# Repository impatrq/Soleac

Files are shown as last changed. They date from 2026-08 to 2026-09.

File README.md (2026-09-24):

<!DOCTYPE html>
<html>
<head>
    <meta charset="UTF-8">

</head>
<body>
    <h1><strong>Soleac</strong></h1>
<p align="center">
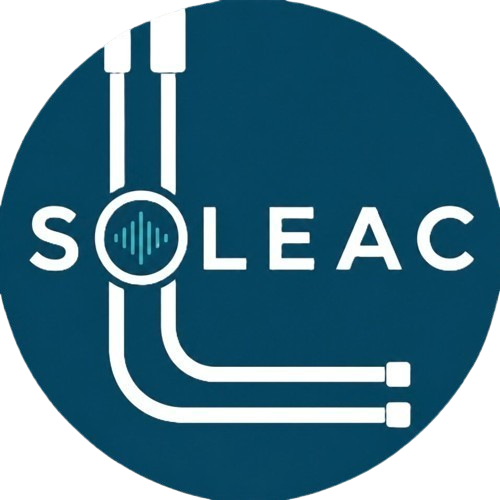
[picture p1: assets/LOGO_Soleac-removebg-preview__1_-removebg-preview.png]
Soleac
  
  &nbsp;&nbsp;&nbsp;&nbsp;
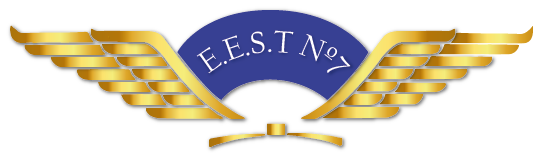
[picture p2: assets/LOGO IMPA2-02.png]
IMPA
  
</p>
</body>
  <h2><strong>Organizacion de archivos</strong></h2>
<em><li><b>Carpeta de campo</b>/Progreso y documentacion </li>
<li><b>Diseño 3D</b>/Diseños fisicos de herraminetas</li>
<li><b>Firmware</b>/Codigos implementados a los microcontroladores</li>
<li><b>Hardware</b></Esquematicos y PCBs</li>
<li><b>Assets</b>/Logotipos, README lockup</li></em>
<hr>
<body>
    <h2><strong>Que es Soleac y cómo funciona</strong></h2>
   <em><b>Soleac es un instrumento tecnologico detector de fugas de aire comprimido y gas. 
   <br>Mediante receptores de frecuencia tales cómo:</b>
   <li>Microfono MEMS SPH0641LU4H-1</li>
    <li>MURATA ma40s4r</li>
<b>Podemos captar fugas en caños, ya que estas generan una frecuencia de entre 20khz y 80khz dependiendo el tamaño.<br>Mediante el siguiente sensor:</b>
 <li>Sensor de gas MQ2</li>
 <b>Al acercar el instrumento, este sensor confirma si realmente hay una fuga, cabe aclarar que solo funciona sensando los siguientes gases:</b>
 <ul>
  <li>Gas Licuado de Petróleo</li>
  <li>Propano</li>
  <li>Metano</li>
  <li>Monóxido de carbono</li>
    <li>butano</li>
</ul>
<b>Si quisieras captar aire comprimido con este sensor, por ejemplo, no sirve y tendrias que usar los sensores de frecuencia.</b></em>
<hr>
<body>
    <h2><strong>Porque existe Soleac</strong></h2>
    <em><b>El instrumento Soleac surge de tres problematicas actuales:</b><br>
    La primera y mas importante es que solo existe una herramienta para los plomeros que les indique con precision donde hay una fuga sin tener que romper ni un ladrillo de pared, la problematica de esta herramienta es que es demasiado cara y ahi es donde entra soleac, presentando un precio que por lo menos este en el presupuesto de un plomero promedio. Llevando a estas herramientas detectores de fugas no solo a empresas grandes, si no tambien a empresas chicas y hogares.</em>
<hr>
<body>
    <h2><strong>Modelo Soleac</strong></h2>
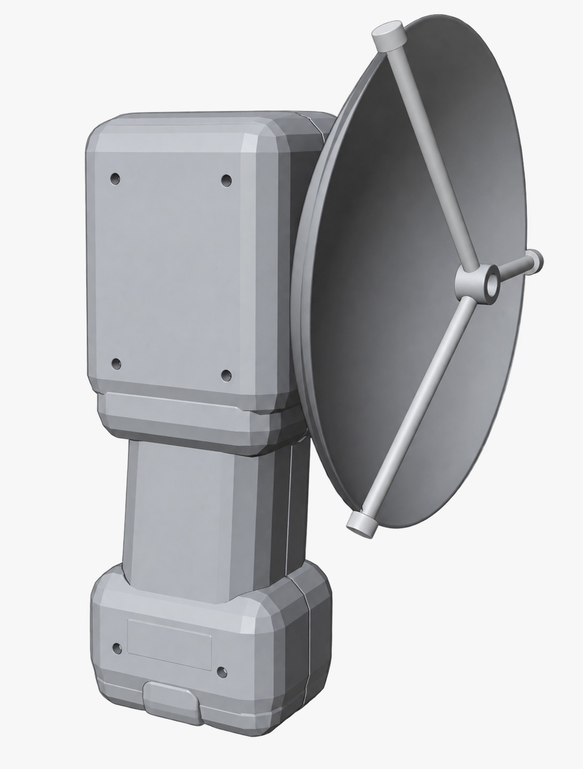
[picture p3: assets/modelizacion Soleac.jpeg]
Soleac

<hr>
<body>
  <h2><strong>Componentes principales del proyecto</strong></h2>
  <em><li>Esp32 S3 Touch Lcd 3.5B</li>
  <li>Microfono MEMS SPH0641LU4H-1</li>
  <li>MURATA ma40s4r</li>
  <li>sensor de gas MQ2</li></em>
</body>
<hr>

<body>
  <h3><strong>Contacto</strong></h3></body>


 

  <h3><strong>Otros proyectos</strong></h3></body>


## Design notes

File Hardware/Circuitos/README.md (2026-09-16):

# Soleac

## En esta carpeta se encuentra el hardware utilizado.
## MQ2-Soleac
MQ2-Back:
* Imagen de la placa de cobre MQ2 del lado de atras.
MQ2-Front:
*Imagen de la placa de cobre MQ2 del lado de adelante.
## Carpeta Placa Mems - SOLEAC
En esta carpeta se guardan los archivos de Kicad de los circuitos esquematicos y PCBs.
Para utilizarlos debes descargar Kicad para poder ver los circuitos y editarlos.
carpeta tal

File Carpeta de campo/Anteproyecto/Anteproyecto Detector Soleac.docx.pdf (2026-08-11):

Escuela de Educación Técnica Nº7
Taller Regional Quilmes
Prácticas Profesionalizantes: Especialidad Aviónica

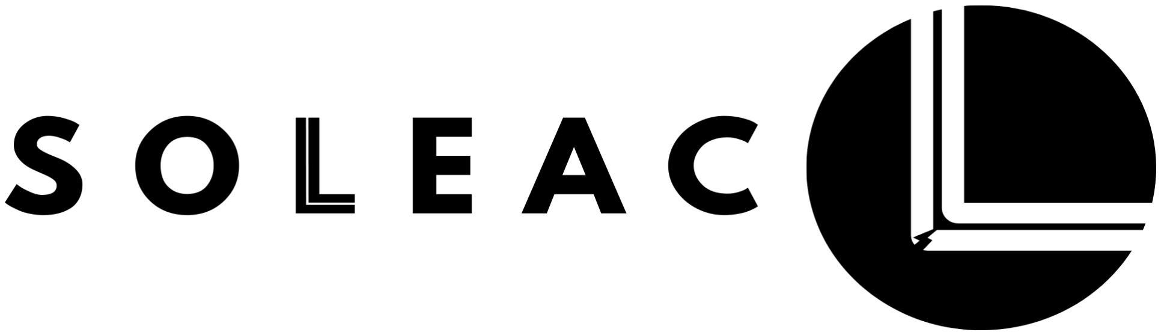
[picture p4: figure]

## Presentación de anteproyecto

## Título del proyecto: “Soleac”

Para pensar el nombre mezclamos tres palabras claves de nuestro proyecto, “Sound” (sonido en inglés), “Sol” (uno de nuestras tipos de alimentación) y “Leak” (Fuga/Derrame en inglés).

## Integrantes:

- Sanabria Caballero Federico ( federico sanabriacaballero )
- Solis Leonard Tobias ( tobias solisleonard )
- Rea Vera Jhonatan ( jhonatan reavera )
- Romero Julian ( julian romero )
- Paolo Valentino ( valentino paolo )

## Objetivo del proyecto:

El objetivo de este proyecto es ayudar a las Pymes, hogares e instalaciones con problemas de fugas en tuberías. Para lograrlo se va a armar un detector de fugas ultrasónico, que mediante sensores ultrasónicos va a poder medir si hay una fuga de gas o aire comprimido. Soleac ayudaría a cuidar el medio ambiente detectando más fácilmente las fugas de gas y aire comprimido y también a empresas/viviendas con ese problema.

## Utilidades del proyecto:

Nuestro proyecto está destinado a las viviendas con instalaciones de gas, a empresas/ fábricas o trabajadores independientes que trabajen con gas o aire comprimido

Las fugas de gas pueden representar pérdidas significativas, variando desde pequeñas ineficiencias hasta un 25% - 30% del volumen en sistemas industriales de aire comprimido, pudiendo superar el 50% en casos graves. En entornos domésticos, una fuga leve es inaceptable, mientras que el riesgo explosivo comienza con un 5% de gas en el aire, un caso reciente es la explosión en una metalúrgica en Tostado o la tragedia en un Polo Industrial en Ezeiza demuestran que las fugas de gas no solo afectan a los trabajadores, sino también a estructuras cercanas.

La OMS (Organización Mundial de la Salud) advierte que el gas deteriora la salud al reaccionar con otros contaminantes para formar ozono troposférico y partículas finas, responsables de muertes por enfermedades respiratorias. Nuestro proyecto ayuda a mejorar el medioambiente impidiendo la contaminación del aire mediante gas.

## Descripción del funcionamiento:

El proyecto consiste básicamente en usar 2 microfonos MEMS ultrasonicos que captaría una señal de 20kHz a 90 kHz, con ayuda de una antena parabólica, medimos y buscamos esas frecuencias ya que son las que usualmente genera la vibración de una fuga de gas o aire comprimido, los 2 sensores sensan la posición exacta o con un margen de error mínimo de donde esta la fuga, lo haríamos gracias a que los microfonos MEMS captan la información y con el tiempo que tarda en llegar la señal se calcula y se consigue la ubicación, el micrófono es muy sensible lo que logra que capte esas señales, las pasaremos por un filtro rechaza-bajos y rechaza-alto que capta las frecuencias anteriormente dichas, después la señal filtrada pasa por un filtrado por tiempo y por un atenuador para poder separar la señal de la fuga de todo el resto y posteriormente pasar por un amplificador con un integrado LM358, después de la etapa de amplificación la señal llega al microcontrolador ESP32 que procesa la información recibida con el ADC, mediante un programa que vamos a crear, y la envía al display LCD y a la aplicación del móvil que muestra la información de donde esta la fuga y de qué fluido se trata.

Para alimentar el detector de fugas va a contar baterías recargables que se cargan con una base de carga que se alimenta con energía solar o alimentación cotidiana (220V), que van a ser elegibles con un switch para usar la más conveniente en la situación que se encuentre el usuario.

## Análisis de factibilidad:

### - Programación del sistema

Integrante: Federico Sanabria Caballero ( federico sanabriacaballero )

Tareas principales:

Programar la lectura de los sensores ultrasónicos, analizar la intensidad de la señal recibida, establecer un umbral de detección de fugas, implementar el cambio de modo (entre gas o aire comprimido), controlar la pantalla LCD, activar alarmas sonoras, enviar datos al celular mediante WiFi y registrar datos en la tarjeta microSD.

Posibles problemáticas y soluciones:

- Ruido en las lecturas del sensor:

Los sensores ultrasónicos pueden captar vibraciones o interferencias.

Soluciones:

Aplicar promedios de lectura

Usar filtros digitales

Ajustar el umbral de detección

- Saturación del ADC

Si la señal amplificada es demasiado grande, el convertidor analógico digital puede saturarse.

Soluciones:

Ajustar la ganancia del amplificador

Usar un divisor de tensión.

- Problemas de sincronización entre sensores

Cuando se usan varios sensores, puede ser difícil comparar señales al mismo tiempo.

Soluciones:

Leer sensores en ciclos rápidos

Usar temporizadores del microcontrolador

- Aplicación de celular

Integrante: Julian Romero ( julian romero )

Tareas principales:

Diseñar la interfaz de la aplicación, recibir datos enviados por el detector y mostrarlos en tiempo real, mostrar alertas de fuga, indicar el sensor que detectó la fuga y mostrar intensidad de la señal.

Posibles problemáticas:

- Dificultad para conectar la app con el ESP32

Puede haber problemas de comunicación entre el celular y el dispositivo.

Soluciones:

Usar protocolos simples como HTTP o WebSocket

Probar primero con una página web local

- Problemas de compatibilidad con celulares

Distintos teléfonos pueden comportarse diferente.

Soluciones:

Usar herramientas multiplataforma

Realizar pruebas en varios dispositivos

- Latencia en la transmisión de datos

Si la conexión es lenta, la información puede tardar en llegar.

Soluciones:

Enviar datos solo cuando hay cambios importantes

Optimizar el tamaño de los mensajes

- Armado físico del dispositivo

Integrantes:

Tobias Solis Leonard ( tobias solisleonard )

Valentino Paolo ( valentino paolo )

Tareas principales:

Diseñar la carcasa del dispositivo, montar los sensores ultrasónicos, instalar la pantalla y botones, armar el sistema de alimentación, organizar el cableado interno y asegurar protección mecánica del circuito.

Posibles problemáticas:

- Posición incorrecta de los sensores

Si los sensores no están bien orientados, la detección puede fallar.

Soluciones:

Probar diferentes posiciones

Usar tubos o guías acústicas para direccionar el sonido

- Vibraciones del dispositivo

Las vibraciones externas pueden afectar la medición.

Soluciones:

Usar soportes de goma

Aislar el sensor del chasis

- Problemas de espacio interno

Muchos componentes pueden dificultar el montaje.

Soluciones:

Diseñar previamente la distribución interna

Usar separadores y soportes

- Diseño de esquemático

Integrante: Jhonatan Nauel Rea Vera ( jhonatan reavera )

Tareas principales:

Diseñar el circuito de amplificación, implementar el filtro pasa banda, conectar sensores al microcontrolador, diseñar la alimentación del sistema y agregar protecciones eléctricas

Posibles problemáticas:

- Diseño incorrecto del filtro

Si el filtro no está bien calculado, puede eliminar la señal de la fuga.

Soluciones:

Simular el circuito antes de construirlo

Verificar frecuencias de corte

- Problemas de ruido eléctrico

Las señales ultrasónicas son muy pequeñas y pueden contaminarse con ruido. Soluciones:

Usar capacitores de desacople

Separar circuitos analógicos y digitales

- Conexiones incorrectas

Errores en el esquemático pueden generar fallas en el circuito.

Solución:

Validar con el equipo antes de fabricar la PCB

- Diseño y armado de PCBs

Integrante: Jhonatan Nauel Rea Vera ( jhonatan reavera )

Tareas principales:
Convertir el esquemático en diseño de PCB, ubicar los componentes correctamente, diseñar pistas de conexión, optimizar el tamaño de la placa y preparar archivos de fabricación.

Posibles problemáticas

- Interferencias entre pistas

Las señales ultrasónicas pueden verse afectadas por ruido de otras líneas.

Soluciones:

Mantener pistas analogicas separadas

- Pistas finitas

Si las pistas son muy delgadas pueden romperse o calentarse.

Soluciones:

Usar ancho adecuado según corriente

Revisar reglas de diseño

- Error en la fabricación

Una PCB mal diseñada puede requerir rehacer la placa.

Soluciones:

Probar primero en protoboard

Revisar el diseño antes de realizarlo

## Costo del proyecto:

Componentes y materiales necesarios:

- Microfono MEMS ultrasonico | $12,50 - $18,00
- Sensores de gas | $4,00 - $6,50
- Panel solar | $10,00 - $35,00
- Display LCD | $6,00 - $9,00
- Componentes básicos (Resistencias, capacitores, transistores, etc.) | $5,00 - $10,00
- LM358 | $0,50 - $1,00
- Adaptador de 220V | $3,00 - $8,00
- Cable de osciloscopio | $15,00 - $25,00
- Filamento para impresión 3D | $18,00 - $24,00
- Protoboard | $5,00 - $8,00
- Placas de cobre | $3,00 - $6,00
- Costo total del proyecto | $82,00 - $150,50

## Análisis de costo/beneficio:

Básicamente Soleac tendría un costo y rentabilidad bastante alto para los estándares actuales que hay en el mismo rubro que este mismo se haya.

Esto se puede comprobar ya que un detector de fugas industrial ronda entre los $2000,00 -$4500,00 mientras que nuestro proyecto ronda entre los $85,50 - $156,00 aproximadamente según las regulaciones y costos que tendríamos durante el proceso de este mismo.

Nuestra idea principal se trataría de que cooperadora pueda invertir en nosotros o en todo caso buscar sponsors qué se dedican a esto mismo, como empresas que refinan gas ayudarían en este proyecto por la única razón que este mismo si llega a ser funcional y rentable estas empresas usarían este mismo proyecto y gastarán menos dinero por ende para ellos generaría una ganancia y reemplazamos algo en el mercado qué tiene un mayor costo y rentabilidad.

## Diagrama en bloques del prototipo:

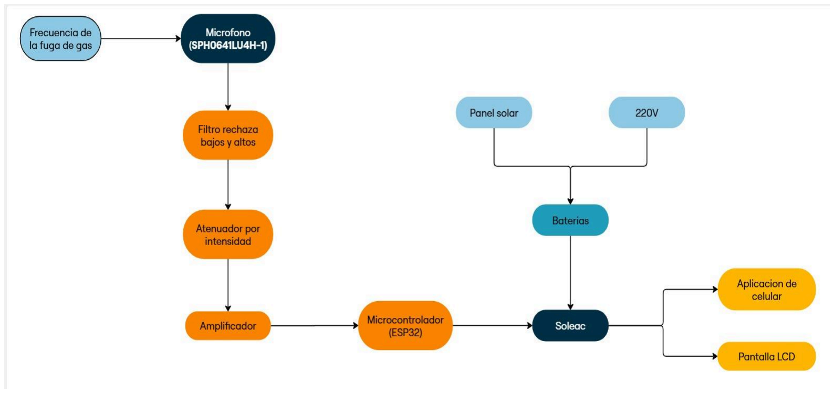
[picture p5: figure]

## Diagrama de tiempo de desarrollo:

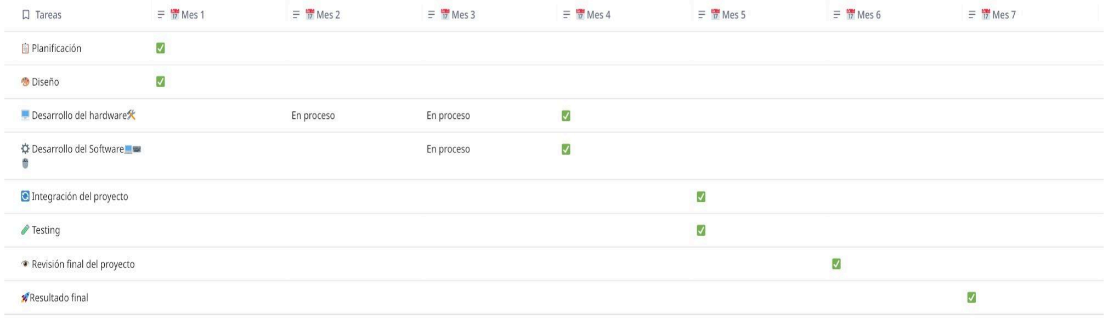
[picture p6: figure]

## Referencias conceptuales:

- https://youtu.be/Gn90nYe9ncI?si=8fitapJfa6MLWlzQ
- https://www.digikey.com/es/products/detail/knowles/SPH0641LU4H-1/5332438
- https://youtu.be/sKoHwYYR5K8?si=CfvAcCGte9ShcVbg
- https://share.google/e64yCyu4zZ64yI810

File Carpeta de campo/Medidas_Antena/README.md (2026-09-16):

# Soleac
## A continuacion se describe lo que contiene esta carpeta

- Aclaraciones antes de empezar a entender como funciona cada calculo sobre la antena, descripciones y frecuencia designada para el detector de fugas.

- Formula de la relación foco y diámetro, formula de la relación longitud de onda y diámetro y factor clave (sensibilidad del microfono).

- Formula de la ganancia, aclaración de signos matemáticos, razonamiento y despeje de la relación F/D, formula de la profundidad de la antena y formula de ancho de haz.

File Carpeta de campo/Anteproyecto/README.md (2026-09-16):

# Soleac

## Dentro de esta carpeta se encuentra el anteproyecto. 

A continuacion se menciona lo que el archivo contiene:

- Objetivo
- Utilidades
- Funcionamiento
- Factibilidad
- Posibles_problematicas_y_soluciones
- Distribucion_de_tareas
- Costos
- Costos/beneficios
- Diagrama_de_bloques_del_prototipo
- Diagrama_de_tiempo_de_desarrollo
- Referencias_conceptuales

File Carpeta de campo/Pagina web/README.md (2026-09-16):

# Soleac 
En esta carpeta se encuentra el codigo que se utiliza para la pagina oficial de Soleac

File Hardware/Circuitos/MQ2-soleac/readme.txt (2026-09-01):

1. Parte de atrás de la placa de cobre del MQ2.

2. Parte de adelante de la placa de cobre del MQ2.

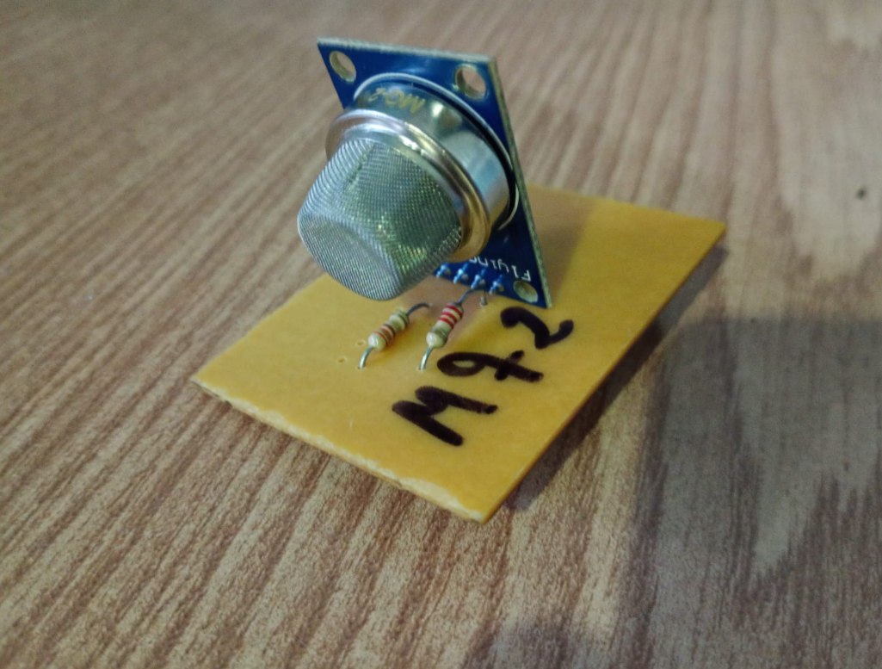
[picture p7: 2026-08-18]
Hardware/Circuitos/MQ2-soleac/MQ2 front.png

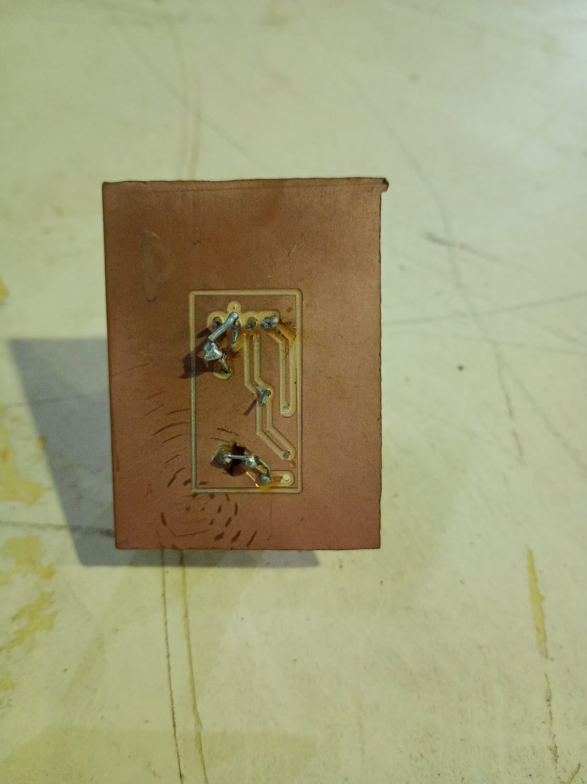
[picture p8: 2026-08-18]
Hardware/Circuitos/MQ2-soleac/MQ2 back.png

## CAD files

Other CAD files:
Diseño 3D/Soleac_Acople_Antena.blend
Diseño 3D/Soleac_Modelo.blend

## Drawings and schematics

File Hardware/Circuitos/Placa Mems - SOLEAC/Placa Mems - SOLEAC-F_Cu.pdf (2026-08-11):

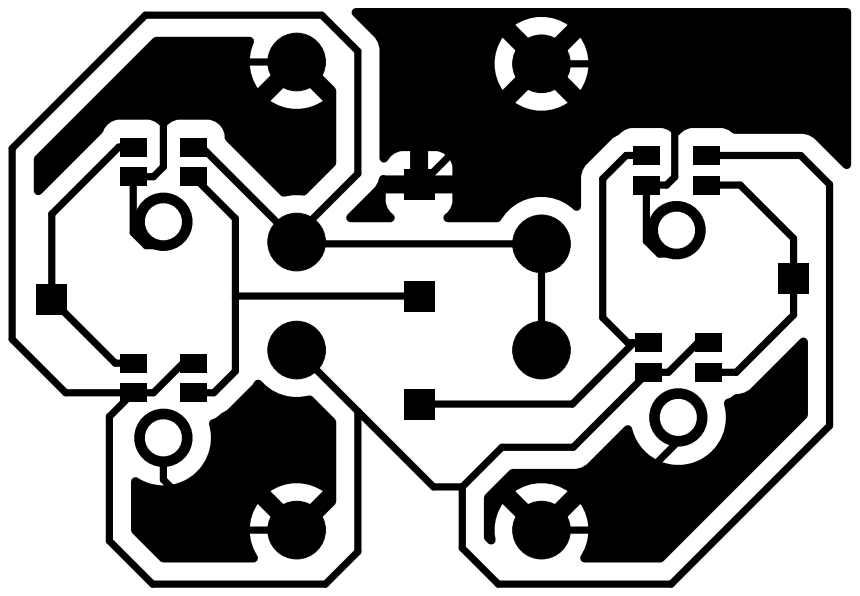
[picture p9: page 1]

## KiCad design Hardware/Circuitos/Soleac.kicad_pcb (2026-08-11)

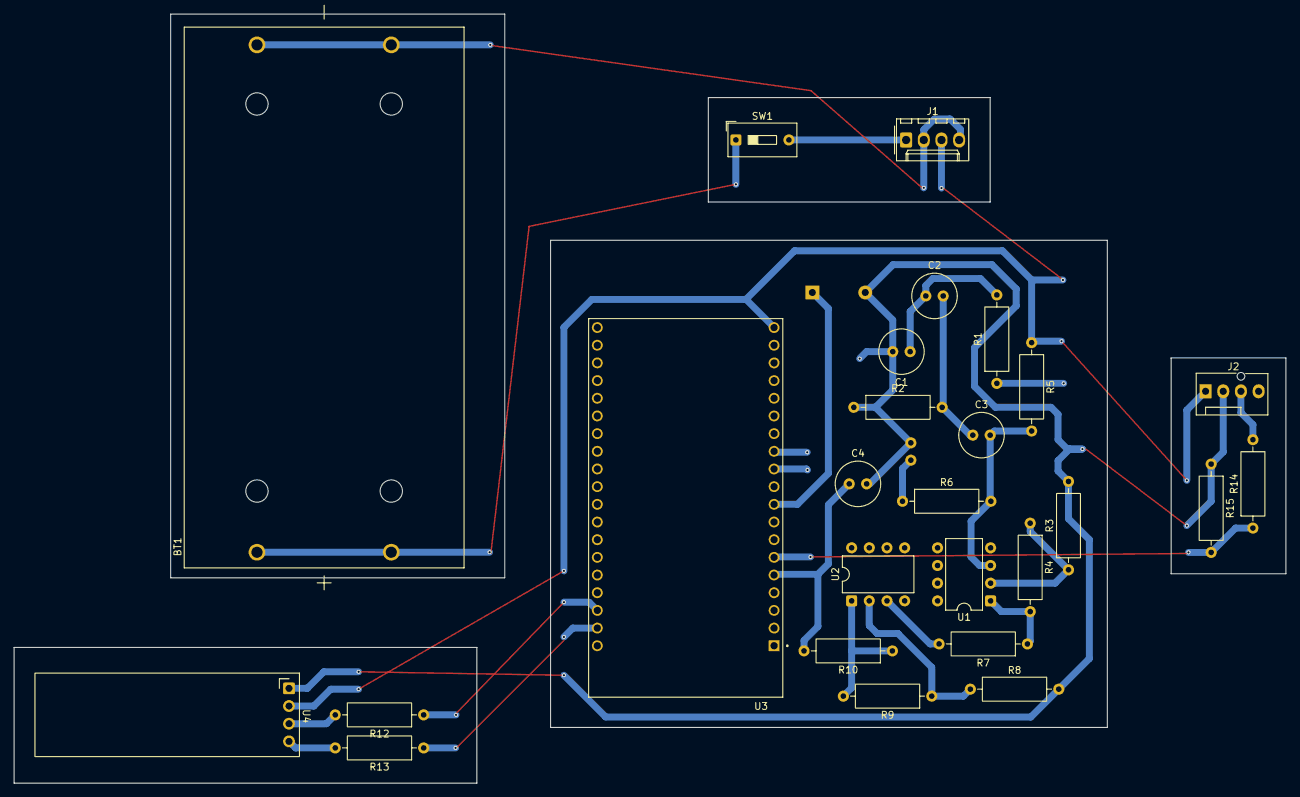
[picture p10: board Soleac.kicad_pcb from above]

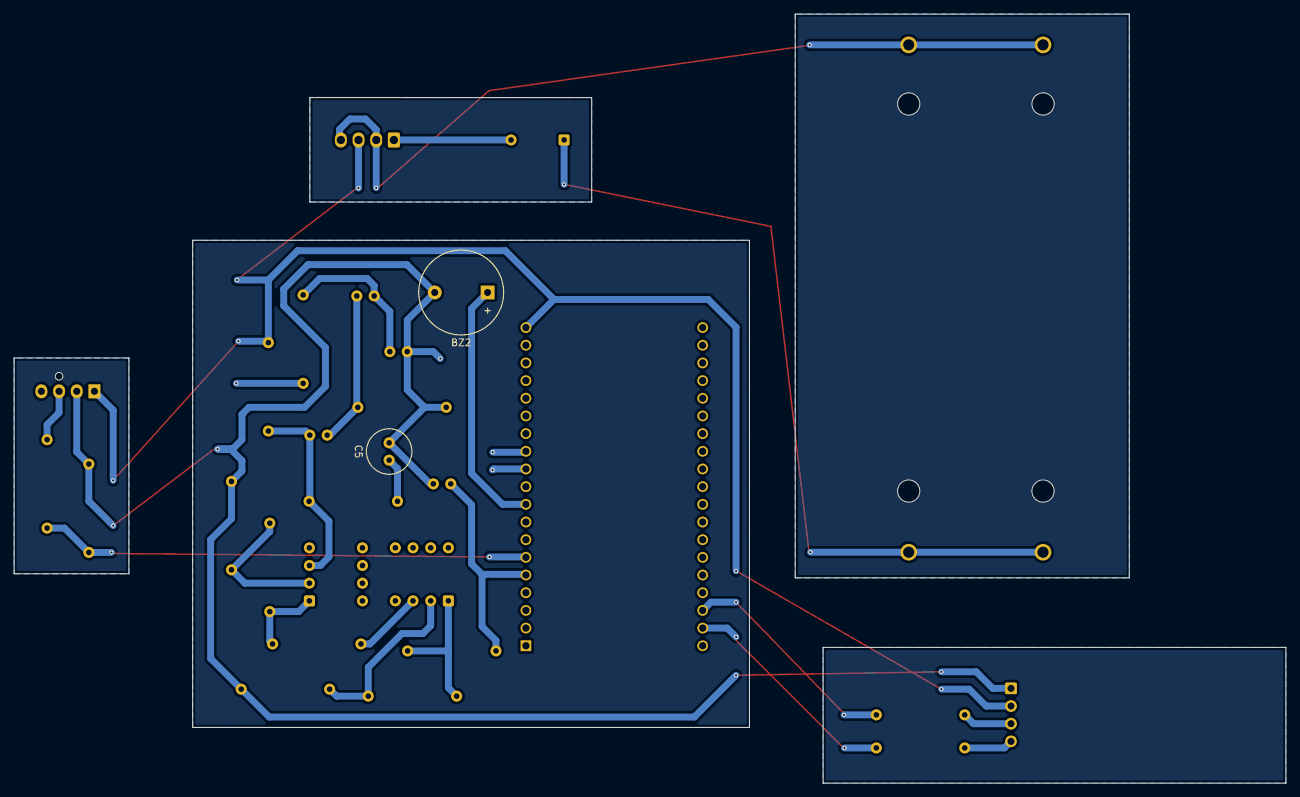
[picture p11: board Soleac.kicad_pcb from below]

Board: 2 copper layers, 182.7 x 110.5 mm, 28 parts (2 on the bottom side), 21 nets.

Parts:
BT1: BK-18650-PC4; BAT_BK-18650-PC4
BZ2: Buzzer; Buzzer_12x9.5RM7.6
C1, C2, C3, C4, C5: C; C_Radial_D6.3mm_H7.0mm_P2.50mm
J1: Regulador de voltaje; Molex_KK-254_AE-6410-04A_1x04_P2.54mm_Vertical
J2: Sensor MQ-2; FanPinHeader_1x04_P2.54mm_Vertical
R1, R2, R3, R4, R5, R6, R7, R8, R9, R10, R12, R13, R14, R15: R; R_Axial_DIN0309_L9.0mm_D3.2mm_P12.70mm_Horizontal
SW1: SW_SPST; SW_DIP_SPSTx01_Slide_9.78x4.72mm_W7.62mm_P2.54mm
U1, U2: LM358; DIP-8_W7.62mm
U3: ESP32-DEVKITC-32D; MODULE_ESP32-DEVKITC-32D
U4: ER_OLEDM0.91_1x-I2C

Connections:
/5V: J1.3, J2.1, R5.1, U3.J2-19 (EXT_5V), U4.2 (VCC)
/GPIO22 (SCL OLED): R12.1, U3.J3-3 (IO22)
/GPIO23 (SDA OLED): R13.1, U3.J3-2 (IO23)
/GPIO25 (BUZZER): BZ2.1 (+), U3.J2-9 (IO25)
/GPIO35 (MQ-2): R14.1, R15.2, U3.J2-6 (IO35)
Earth: BT1.1-, BT1.2-, BZ2.2 (-), C1.2, C4.2, C5.2, J1.2, J1.4, J2.2, R2.1, R3.2, R8.2, R15.1, U4.1 (GND)
unnamed: C1.1, C2.1, R1.2
unnamed: C2.2, C3.1, R2.2
unnamed: C5.1, R6.1
unnamed: J1.1, SW1.2 (B)
unnamed: J2.3, R14.2
unnamed: R4.2, R7.1, U1.1
unnamed: R9.2, R10.1, U2.1
unnamed: BT1.1+, BT1.2+, SW1.1 (A)
unnamed: C3.2, R5.2, R6.2, U1.3 (+)
unnamed: R3.1, R4.1, U1.2 (-)
unnamed: R7.2, U2.3 (+)
unnamed: R8.1, R9.1, U2.2 (-)
unnamed: C4.1, R10.2, U3.J2-5 (IO34)
unnamed: R12.2, U4.3 (SCL)
unnamed: R13.2, U4.4 (SDA)

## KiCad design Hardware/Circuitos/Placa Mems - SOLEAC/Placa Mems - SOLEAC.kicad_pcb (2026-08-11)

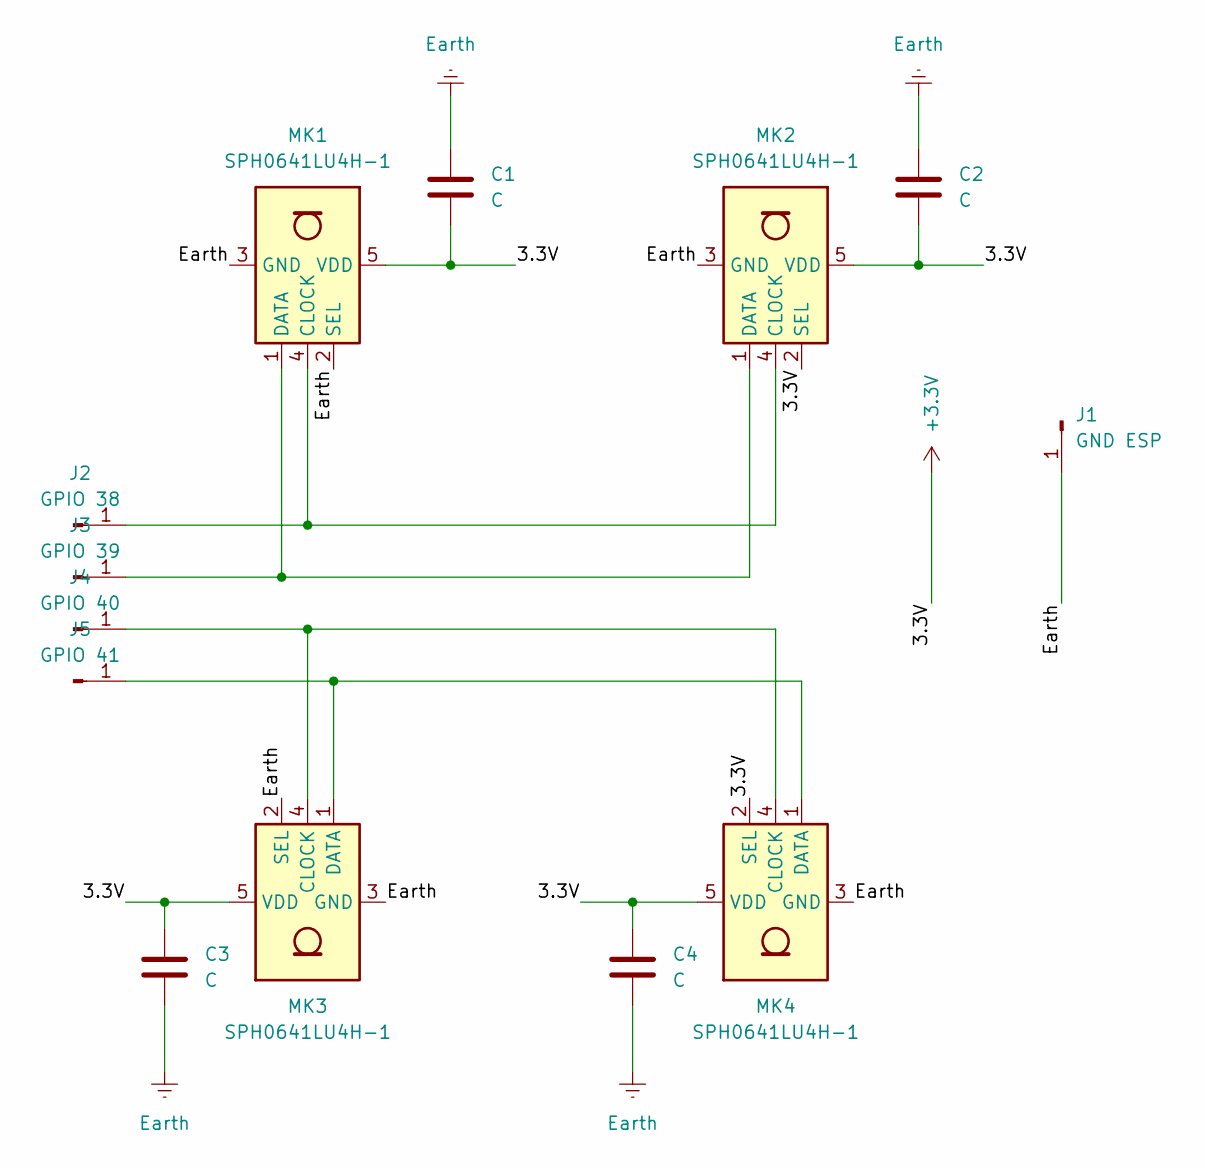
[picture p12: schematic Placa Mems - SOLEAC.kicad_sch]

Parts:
C1, C2, C3, C4: C; C_Disc_D4.3mm_W1.9mm_P5.00mm
J1: GND ESP; PinHeader_1x01_P1.00mm_Vertical
J2: GPIO 38; PinHeader_1x01_P1.00mm_Vertical
J3: GPIO 39; PinHeader_1x01_P1.00mm_Vertical
J4: GPIO 40; PinHeader_1x01_P1.00mm_Vertical
J5: GPIO 41; PinHeader_1x01_P1.00mm_Vertical
MK1, MK2, MK3, MK4: SPH0641LU4H-1; Knowles_LGA-5_3.5x2.65mm

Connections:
+3.3V: C1.2, C2.2, C3.1, C4.1, MK1.5 (VDD), MK2.2 (SEL), MK2.5 (VDD), MK3.5 (VDD), MK4.2 (SEL), MK4.5 (VDD)
Earth: C1.1, C2.1, C3.2, C4.2, J1.1 (Pin_1_1), MK1.2 (SEL), MK1.3 (GND), MK2.3 (GND), MK3.2 (SEL), MK3.3 (GND), MK4.3 (GND)
unnamed: J2.1 (Pin_1_1), MK1.4 (CLOCK), MK2.4 (CLOCK)
unnamed: J3.1 (Pin_1_1), MK1.1 (DATA), MK2.1 (DATA)
unnamed: J4.1 (Pin_1_1), MK3.4 (CLOCK), MK4.4 (CLOCK)
unnamed: J5.1 (Pin_1_1), MK3.1 (DATA), MK4.1 (DATA)

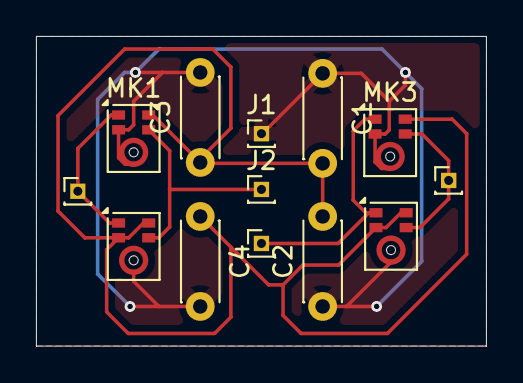
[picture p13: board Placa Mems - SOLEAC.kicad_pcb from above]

Board: 2 copper layers, 25.0 x 17.2 mm, 13 parts (0 on the bottom side), 6 nets.

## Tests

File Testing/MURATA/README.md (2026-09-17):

# Soleac
## En esta carpeta se encuentra la descripcion y evidencia de prueba.

1. Probamos el microfono murata con un kicad amplificador de filtros en protoboard. Funciono por un momento pero se genera mucho ruido, para eso necesitamos pasar al siguiente paso, placa de cobre.

2. Probamos placa de filtros con el microfono murata y una frecuencia de 40khz proveniente de un telefono celular.

3. Proyectar por qué en la terminal se excede del límite representable 4096 en función de la tensión que le llega un pin de la esp32.

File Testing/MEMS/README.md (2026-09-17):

# Soleac
## En esta carpeta se encuentra una descri[pcion breve y fotos de la prueba realizada.

1. Probamos el microfono mems con ruido ambiente, le inyectamos señal de clock de 2.2Mhz y conectamos 3,3v de la esp32.

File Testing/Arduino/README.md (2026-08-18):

# Test_Arduino

Dentro de esta carpeta se encuetran pruebas realizadas en Arduino IDE.
Estas pruebas estan hechas para que la applicacion movil de Flutter detecte las frecuencias y las muestre en forma de dB (Ganancia). 
A continuacion se describe lo que contiene cada archivo:
#
## 1_envio_de_datos 
 Configura la ESP32 como dispositivo BLE llamado SOLEAC y envía datos simulados a la aplicación Flutter. La intensidad hf sube y baja entre 25 y 75, generando una alarma cuando supera el umbral de 60.

## 2_recepcion_de_frecuencia:
 Prueba básica del micrófono MAX4466. Lee directamente el valor analógico del pin 34 y lo muestra por el monitor serial.

## 3_recepcion_de_frecuencia:
Primera versión funcional con micrófono y BLE.
Toma 300 muestras del MAX4466.

-Calcula el valor pico a pico de la señal.

-Convierte ese valor a una escala aproximada de intensidad hf entre 0 y 100.

-Compara la intensidad con el umbral de 60.

-Envía los datos a Flutter mediante BLE en formato CSV:

## 4_recepcion_de_frecuencia:
 Hace lo mismo que 3_recepcion_de_frecuencia, pero:

-Muestra también peakToPeak por el monitor serial.

-Usa un rango de conversión diferente, de 0 a 250.

-Reinicia el advertising BLE continuamente cuando no hay conexión.

-Envía el mismo formato CSV compatible con Flutter.

## 5_lcd_aparte:Es una prueba independiente de la pantalla LCD del dispositivo ESP32-S3.

-Inicializa la pantalla mediante QSPI.

-Configura el expansor I²C TCA9554.

-Activa la retroiluminación.

-Comprueba la PSRAM.

-Muestra los textos SOLEAC, LCD OK, ESP32-S3 y PSRAM OK.

## libraries: 
Librerias necesarios para los  upload.
# Como probar estos codigos
Para subir el codigo a la Esp32, se debe conectar mediante un usb en algun puerto que posea su PC y haga click en upload.

Para mostrar lo que recibe la ESP32, debera abrir el monitor en Arduino IDE en 115200 bau

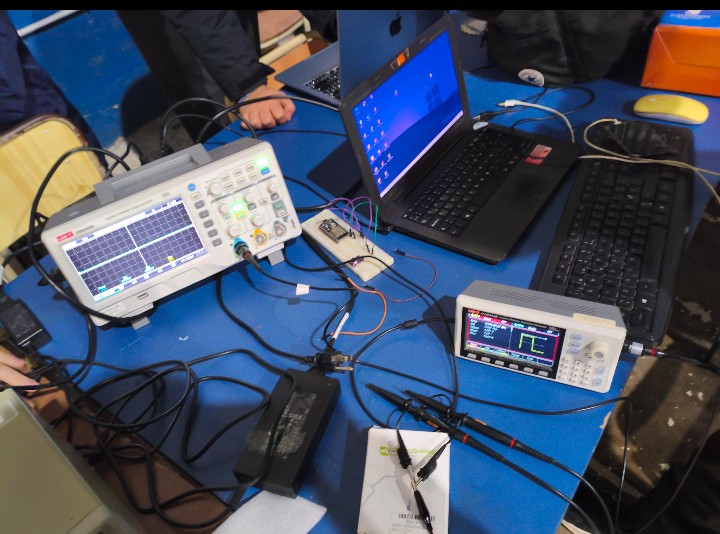
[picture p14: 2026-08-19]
Testing/MEMS/test mems 0508.png

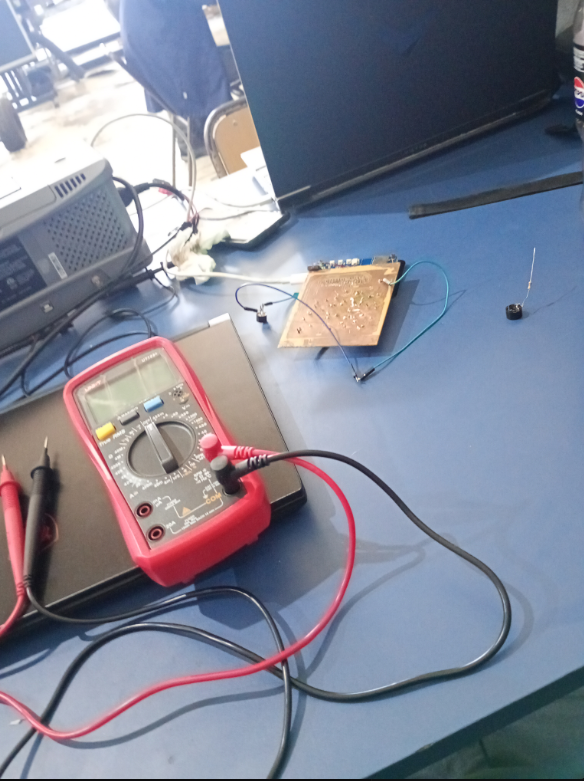
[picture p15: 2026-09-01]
Testing/MURATA/Captura de pantalla 2026-09-01 082249.png

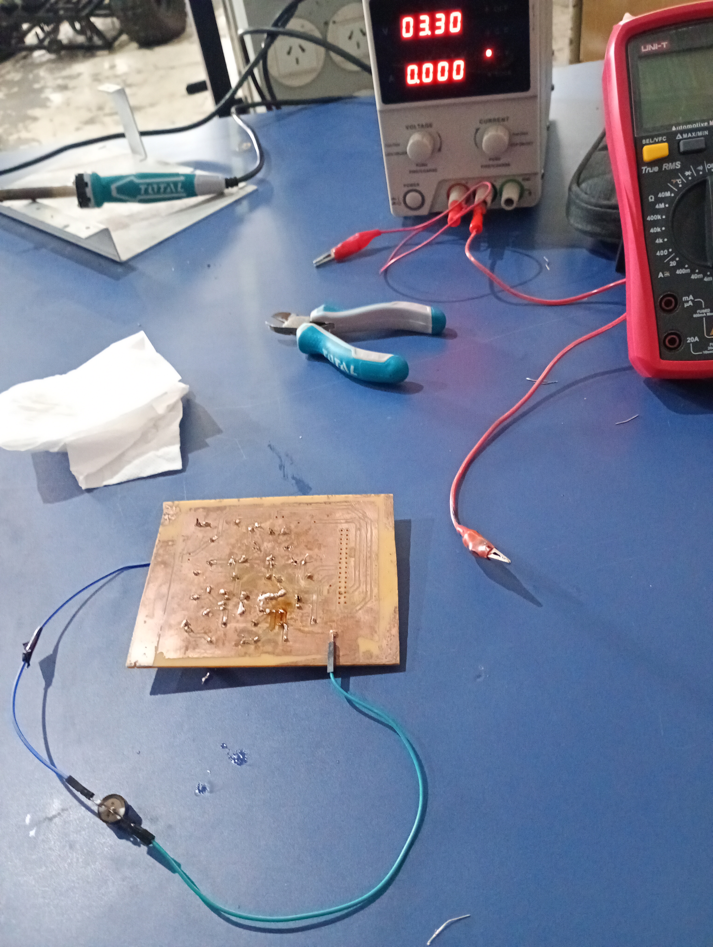
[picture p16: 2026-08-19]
Testing/MURATA/test murata 1808.jpg

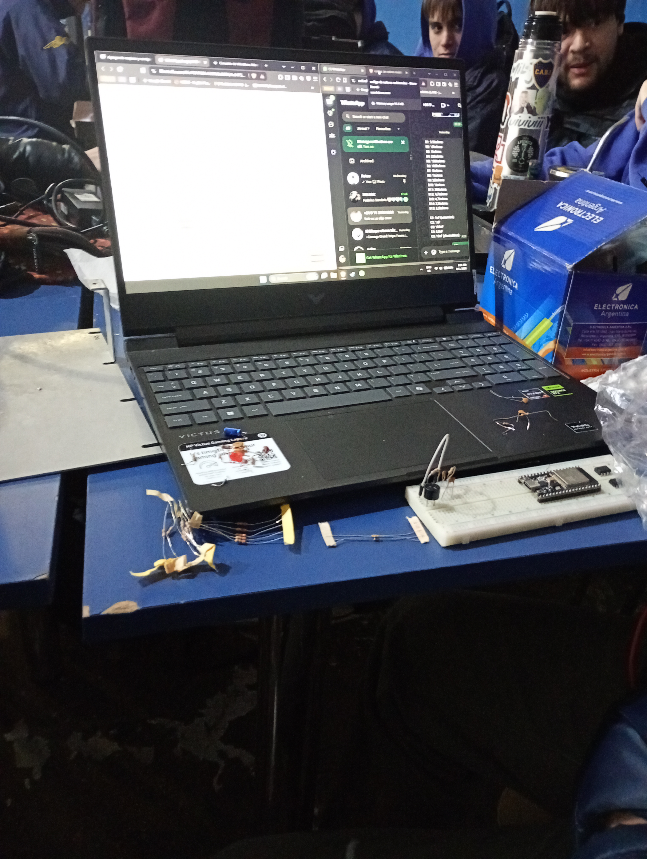
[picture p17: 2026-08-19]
Testing/MURATA/test murata 1108.jpg

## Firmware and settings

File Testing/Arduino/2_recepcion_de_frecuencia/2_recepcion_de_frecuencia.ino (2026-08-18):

#include <NimBLEDevice.h>
#include <math.h>

#define DEVICE_NAME "SOLEAC"

#define SERVICE_UUID        "12345678-1234-5678-1234-56789abcdef0"
#define TELEMETRY_CHAR_UUID "12345678-1234-5678-1234-56789abcdef1"

const int MIC_PIN = 34;

const float threshold = 60.0;

NimBLECharacteristic* telemetryCharacteristic;
bool deviceConnected = false;

class ServerCallbacks : public NimBLEServerCallbacks {
  void onConnect(NimBLEServer* server) {
    deviceConnected = true;
    Serial.println("Celular conectado por BLE");
  }

  void onDisconnect(NimBLEServer* server) {
    deviceConnected = false;
    Serial.println("Celular desconectado. Reiniciando advertising...");
    delay(500);
    NimBLEDevice::startAdvertising();
  }
};

float readMicLevel() {
  const int samples = 300;

  int minValue = 4095;
  int maxValue = 0;

  for (int i = 0; i < samples; i++) {
    int value = analogRead(MIC_PIN);

    if (value < minValue) {
      minValue = value;
    }

    if (value > maxValue) {
      maxValue = value;
    }

    delayMicroseconds(150);
  }

  int peakToPeak = maxValue - minValue;

  float hf = map(peakToPeak, 0, 600, 20, 95);
  hf = constrain(hf, 0, 100);

  return hf;
}

void setup() {
  Serial.begin(115200);
  delay(1000);

  analogReadResolution(12);
  analogSetPinAttenuation(MIC_PIN, ADC_11db);

  Serial.println("Iniciando SOLEAC BLE + microfono...");

  NimBLEDevice::init(DEVICE_NAME);

  NimBLEServer* server = NimBLEDevice::createServer();
  server->setCallbacks(new ServerCallbacks());

  NimBLEService* service = server->createService(SERVICE_UUID);

  telemetryCharacteristic = service->createCharacteristic(
    TELEMETRY_CHAR_UUID,
    NIMBLE_PROPERTY::READ | NIMBLE_PROPERTY::NOTIFY
  );

  telemetryCharacteristic->setValue("20.0,60.0,0,1");

  service->start();

  NimBLEAdvertising* advertising = NimBLEDevice::getAdvertising();
  advertising->addServiceUUID(SERVICE_UUID);
  advertising->setName(DEVICE_NAME);
  advertising->start();

  Serial.println("BLE listo. Buscar SOLEAC desde la app.");
}

void loop() {
  float hf = readMicLevel();
  bool alarm = hf >= threshold;

  String payload = "";
  payload += String(hf, 1);
  payload += ",";
  payload += String(threshold, 1);
  payload += ",";
  payload += alarm ? "1" : "0";
  payload += ",";
  payload += "1";

  telemetryCharacteristic->setValue(payload.c_str());

  if (deviceConnected) {
    telemetryCharacteristic->notify();
  }

  Serial.print("payload: ");
  Serial.println(payload);

  delay(500);
}

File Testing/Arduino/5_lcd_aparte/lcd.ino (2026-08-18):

#include <Arduino.h>
#include <Wire.h>
#include <Arduino_GFX_Library.h>
#include "TCA9554.h"

// Pines de la pantalla QSPI
#define LCD_QSPI_CS   12
#define LCD_QSPI_CLK   5
#define LCD_QSPI_D0    1
#define LCD_QSPI_D1    2
#define LCD_QSPI_D2    3
#define LCD_QSPI_D3    4

// Retroiluminación
#define LCD_BACKLIGHT 6

// I2C del expansor TCA9554
#define I2C_SDA 21
#define I2C_SCL 22

TCA9554 tca(0x20);

// Bus QSPI de la pantalla
Arduino_DataBus* bus = new Arduino_ESP32QSPI(
  LCD_QSPI_CS,
  LCD_QSPI_CLK,
  LCD_QSPI_D0,
  LCD_QSPI_D1,
  LCD_QSPI_D2,
  LCD_QSPI_D3
);

// Controlador AXS15231B de la pantalla
Arduino_GFX* display = new Arduino_AXS15231B(
  bus,
  GFX_NOT_DEFINED,
  0,
  false,
  320,
  480
);

// Canvas usando la PSRAM
Arduino_Canvas* gfx = new Arduino_Canvas(
  320,
  480,
  display,
  0,
  0,
  0
);

void setup() {
  Serial.begin(115200);
  delay(1500);

  Serial.println();
  Serial.println("================================");
  Serial.println("Prueba LCD ESP32-S3 SOLEAC");
  Serial.println("================================");

  Serial.print("PSRAM encontrada: ");
  Serial.println(psramFound() ? "SI" : "NO");

  Serial.print("PSRAM total: ");
  Serial.print(ESP.getPsramSize() / 1024);
  Serial.println(" KB");

  Serial.print("Heap libre: ");
  Serial.print(ESP.getFreeHeap() / 1024);
  Serial.println(" KB");

  Serial.println("Inicializando I2C...");

  Wire.begin(I2C_SDA, I2C_SCL);

  Serial.println("Inicializando TCA9554...");

  tca.begin();

  // Control de alimentación/backlight mediante el expansor
  tca.pinMode1(1, OUTPUT);

  tca.write1(1, 1);
  delay(10);

  tca.write1(1, 0);
  delay(10);

  tca.write1(1, 1);
  delay(200);

  Serial.println("Activando retroiluminacion...");

  pinMode(LCD_BACKLIGHT, OUTPUT);
  digitalWrite(LCD_BACKLIGHT, HIGH);

  Serial.println("Inicializando controlador LCD...");

  if (!gfx->begin()) {
    Serial.println("ERROR: no se pudo inicializar el canvas/LCD");
    return;
  }

  Serial.println("LCD inicializado correctamente");

  gfx->fillScreen(RGB565_BLUE);

  gfx->setTextColor(RGB565_WHITE);
  gfx->setTextSize(4);
  gfx->setCursor(30, 60);
  gfx->println("SOLEAC");

  gfx->setTextSize(3);
  gfx->setCursor(30, 140);
  gfx->println("LCD OK");

  gfx->setTextColor(RGB565_YELLOW);
  gfx->setCursor(30, 210);
  gfx->println("ESP32-S3");

  gfx->setTextColor(RGB565_GREEN);
  gfx->setCursor(30, 280);
  gfx->println("PSRAM OK");

  // Envía el contenido del canvas a la pantalla
  gfx->flush();

  Serial.println("Texto enviado al LCD");
  Serial.println("Prueba terminada");
}

void loop() {
  delay(1000);
}

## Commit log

2026-04-15 medidas de la antena
2026-05-29 Colocación de base
    [Soleac_Modelo.blend]
2026-05-29 Colocación de soporte del mango
    [Soleac_Modelo.blend]
2026-05-29 Colocación de mango
    [Soleac_Modelo.blend]
2026-05-29 Colocación del segundo soporte
    [Soleac_Modelo.blend]
2026-05-29 Colocación de la zona de la pantalla OLED
    [Soleac_Modelo.blend]
2026-05-29 Colocación de soporte de la pantalla OLED
    [Soleac_Modelo.blend]
2026-06-09 feat: implementar codigo de interfaz a la app movil Soleac
2026-07-14 Modelado 3D
    [Soleac_Acople_Antena.blend, Soleac_Modelo.blend]
2026-07-14 primera mitad soleac
    [Soleac_Modelo.blend]
2026-07-14 segunda mitad del dispositivo
    [Soleac_Modelo.blend]
2026-07-14 primer orificio de los tornillos
    [Soleac_Modelo.blend]
2026-07-14 Segundo orificio de los tornillos
    [Soleac_Modelo.blend]
2026-07-14 Tercer orificio de los tornillos
    [Soleac_Modelo.blend]
2026-07-14 Cuarto orificio de los tornillos
    [Soleac_Modelo.blend]
2026-07-14 Quinto orificio de los tornillos
    [Soleac_Modelo.blend]
2026-07-14 Ultimo orificio de los tornillos
    [Soleac_Modelo.blend]
2026-07-14 Colocacion de los mitades
    [Soleac_Modelo.blend]
2026-08-18 MQ2 Back
    back de la placa de cobre del MQ2
2026-08-18 MQ2 front
    Placa de cobre de la placa MQ2
2026-08-18 Update README.md with MQ2 image descriptions
    Added descriptions for the MQ2 copper board images.
2026-08-18 Update README with SOLEAC folder details
    Added information about the SOLEAC folder and Kicad usage.
2026-08-19 test murata
    probamos placa de filtros con el microfono murata y una frecuencia de 40khz proveniente de un telefono celular.
2026-08-19 test murata
    probamos el microfono murata con un kicad amplificador de filtros en protoboard. Funciono por un momento pero se genera mucho ruido, para eso necesitamos pasar al siguiente paso, placa de cobre.
2026-08-19 test mems
    probamos el microfono mems con ruido ambiente, le inyectamos señal de clock de 2.2Mhz y conectamos 3,3v de la esp32.
2026-08-19 readme
    desc de las fotos
2026-09-01 test error 4096 en ESP32
    error 4096: cantidad excedida de "x" cosa. Invesitigamos voltaje.
2026-10-23 Nueva pagina web
    Cambio de codigo por una pagina nueva y mas didactica
2026-10-26 Create readme.md for SOLEAC hardware documentation
    Added documentation for backup files and PCB generation.
2026-10-26 Archivos placas
    Todos los archivos de las placas hasta la fecha 26/10
2026-10-26 Placa ESP32-S3
2026-10-26 Placa procesadora - Colocación de filtro
2026-10-26 Placa procesadora - Conexión de filtros
2026-10-26 Placa procesadora - Componentes adaptación ESP32
2026-10-26 Placa procesadora - Borde de placa
2026-10-26 Placa procesadora - Componentes en PCB
2026-10-26 Placa procesadora - Conexión componentes PCB
2026-10-26 Placa procesadora - Zona de tierra PCB
2026-10-26 Placa Mems - Margen de la placa
2026-10-26 Placa Mems - Componentes PCB
2026-10-26 Placa Mems - Ruteo de PCB
2026-10-26 Placa Mems - Zona de tierra
2026-10-26 Borrar archivos que sobran
2026-10-26 Placa ESP32 - Cambio de huella bornera
2026-10-26 Placa ESP32 - Actualizar huella en PCB
2026-10-27 Placa procesadora - Muescas para placas
2026-10-27 Placa procesadora - Arreglar margenes de tierra
2026-10-27 Placa procesadora - Corrección de tamaño
2026-10-27 Placa Mems - Asignación de huella
2026-10-27 Placa Mems - Corrección de pines
2026-10-27 Placa MQ9 - Divisor de tension y IN 5V
2026-10-27 Placa MQ9 - Colocar OUT a ESP32
2026-10-27 Placa MQ9 - Asignación de huellas
2026-10-27 Placa MQ9 - Corrección de huella
2026-10-27 Placa MQ9 - Colocación de componentes
2026-10-27 Placa MQ9 - Ruteo PCB
2026-10-27 Documentacion de la app movil
2026-10-27 Placa ESP32 - Colocar componentes en la PCB
2026-10-27 Placa ESP32 - Rutear componentes
2026-10-27 Placa ESP32 - Corrección de pista
2026-10-28 Ignora artefactos locales de ESP-IDF
2026-10-28 Define el proyecto ESP-IDF SOLEAC
2026-10-28 Documenta el entorno de compilacion del firmware
2026-10-28 Fija versiones de dependencias ESP-IDF
2026-10-28 Agrega valores predeterminados de ESP32-S3
2026-10-28 Agrega punto de entrada de la aplicacion
2026-10-28 Declara interfaz de comunicacion BLE
2026-10-28 Agrega control de pantalla LCD y tactil
2026-10-28 Declara interfaz de control LCD
2026-10-28 Agrega registro de mediciones en tarjeta SD
2026-10-31 Create readme.md for ESP32-S3 firmware
    Added documentation for firmware files and structure.
2026-10-31 Create readme.md for hardware circuit documentation
    Added a readme file with descriptions of hardware components.
2026-10-31 Fix formatting in readme.md for circuit files
2026-10-31 Add README with ESP32 board files description
2026-10-31 Create readme for Soleac library
    Added a readme file for the MEMS board library.
2026-10-31 Add README with file descriptions for PCB project
2026-10-31 Add readme.md for MQ-9 gas sensor files
2026-10-31 Rename Captura de pantalla 2026-09-01 082249.png to murata en protoboard
2026-11-04 Correct sensor names in README.md
    Updated sensor names for accuracy in the README.
